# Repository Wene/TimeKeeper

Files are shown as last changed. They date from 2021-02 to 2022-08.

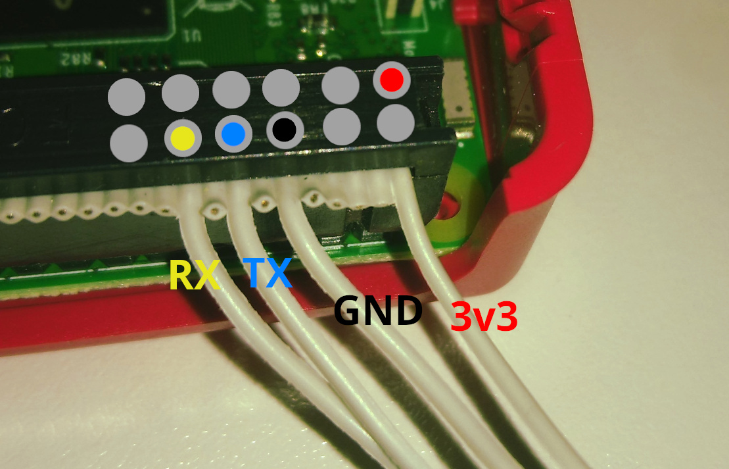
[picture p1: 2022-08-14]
img/Raspi_connector_with_description.jpg

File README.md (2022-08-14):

# TimeKeeper

## Project Goal

An open source, simple, and cheap solution for work time collection.

## Components

Every TimeKeeper collection point is equipped with a Raspberry Pi and some electronic components for RFID communication. In the only so far implemented version, those are a display and an RFID reader for the communication with the users and an Arduino to abstract the communication between the other electronic components and the Raspberry Pi. (See the schematics below)

Then, there is a desktop software written in Python using the PyQt libraries to view and manage the data. It's quite minimal at the moment. But as usage grows, the desktop client should be able to grow as well.

### Arduino Abstraction

The abstraction over the Arduino was chosen because there are some well established libraries available to interface with the display and the RFID reader. Of course, on the Raspberry Pi there are also libraries available to communicate directly with those components. But those aren't part of the main OS distribution. So on every update, we would have to take care to maintain compatibility. And since the Raspberrys are connected to the network, keeping them up to date is highly recommended. The serial interface used to communicate to the Arduino is part of the main distribution. On the other hand, the Arduino is not connected to the network and therefore less susceptible to attacks. And those libraries are way better integrated and available for a wide range of components in Arduino and PlatformIO. So in the future it should be simple to extend the system by other display and RFID reader types by just small changes in the PlatformIO code.

## Schematics

```
                  ┌───────────────────────────────────────────────────┐
                  │                                                   │
                  │            ┌──────────────────────────────────────┼──┐
                  │            │                                      │  │
┌─────────────────┴────────┐   │              ┌──────────────────┐    │  │
│                          │   │              │                  │    │  │
│                3v3   5v0 │   │              │ Arduino          │    │  │
│                          │   │              │ Pro Mini         │    │  │
│                      5v0 │   │              │ 328P 3v3 8 MHz   │    │  │
│   Raspberry Pi           │   │              │                  │    │  │
│                      GND ├───┘        ┌─────┤ TX               │    │  │
│                          │            │     │                  │    │  │
│                      TXD ├────────────┼─────┤ RX           GND ├────┼──┤
│                          │            │     │                  │    │  │
│                      RXD ├────────────┘     │                  │    │  │
│                          │                  │                  │    │  │
│                          │                  │              VCC ├────┤  │
└──────────────────────────┘                  │                  │    │  │
                                              │                  │    │  │                      ┌───────────────────────┐
                                        ┌─────┼─── A5 (SCL)      │    │  │                      │                       │
┌─────────────────────────────┐         │     │               10 ├────┼──┼──────────────────────┤ SDA                   │
│                             │         │  ┌──┼─── A4 (SDA)      │    │  │                      │                       │
│                         GND ├──────┐  │  │  │               11 ├────┼──┼───────────────┐  ┌───┤ SCK                   │
│                             │      │  │  │  │                  │    │  │               │  │   │                       │
│                         VCC ├───┐  │  │  │  │               12 ├────┼──┼────────────┐  └──┼───┤ MOSI                  │
│ Display (3V3 tolerant)      │   │  │  │  │  │                  │    │  │            │     │   │                       │
│                         SDA ├───┼──┼──┼──┘  │               13 ├────┼──┼─────────┐  └─────┼───┤ MISO                  │
│                             │   │  │  │     │                  │    │  │         │        │   │           RFID-RC522  │
│                         SCL ├───┼──┼──┘     │               A0 ├────┼──┼──────┐  └────────┘   │ IRQ                   │
│                             │   │  │        │                  │    │  │      │               │                       │
└─────────────────────────────┘   │  │        └──────────────────┘    │  ├──────┼───────────────┤ GND                   │
                                  │  │                                │  │      │               │                       │
                                  │  └────────────────────────────────┼──┘      └───────────────┤ RST                   │
                                  │                                   │                         │                       │
                                  └───────────────────────────────────┴─────────────────────────┤ 3v3                   │
                                                                                                │                       │
                                                                                                └───────────────────────┘
```

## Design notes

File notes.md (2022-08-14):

# Notes for project TimeKeeper

## Raspberry Pi

### Links
- [UART configuration](https://www.raspberrypi.com/documentation/computers/configuration.html#configuring-uarts)
- [GPIO general](https://www.raspberrypi.com/documentation/computers/os.html#gpio-and-the-40-pin-header)
- [Pin header schema](https://www.raspberrypi.org/documentation/hardware/raspberrypi/schematics/rpi_SCH_3bplus_1p0_reduced.pdf)

### Activating UART on GPIO header
Execute `raspi-config` and navigate to `3 interface options > Serial`. Here enable the UART interface but disable the default console on it. Reboot the RasPi after finishing those settings. To access the UART serial interface, the user needs to be in the groups `dialout` and `tty`.

### Test the connection
Use the command `screen /dev/ttyS0 115200` to open a screen session on the embedded UART serial interface at 115200 baud. Make sure something like an FTDI USB adapter is connected to that interface and configured to use the same data rate. You can now type in the screen session and your input should appear on the other side and vice versa.

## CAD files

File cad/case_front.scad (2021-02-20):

$fn = 100; 

module display_cut(){
    width = 72;
    height = 25;
    depth = 7;
    translate([-width/2, -height/2, 0]) cube([width, height, depth]);

    border = 8;
    top_width = width + 2*border;
    top_height = height + 2*border;
    top_thick = 10;
    translate([-top_width/2, -top_height/2, depth]) cube([top_width, top_height, top_thick]);

    step = 4;
    step_width = width-4;
    step_height = height-4;
    translate([-top_width/2, -step_height/2, step]) cube([top_width, step_height, top_thick]);
    translate([-step_width/2, -top_height/2, step]) cube([step_width, top_height, top_thick]);
}

module reader_dent(){
    width = 60 + 1;
    height = 40 + 1;
    depth = 1.6;
    pin_depth = 4;
    pin_width = 11;
    translate([-width/2, -height/2, -depth]) cube([width, height, depth]);
    translate([-width/2, -height/2, -pin_depth]) cube([pin_width, height, pin_depth]);
    translate([width/2-pin_width, -height/2, -pin_depth]) cube([pin_width, height, pin_depth]);
}

module case_front(){
    wall = 8;
    inner_width = 110;
    width = inner_width + 2*wall;
    inner_height = 100;
    height = inner_height + 2*wall;
    depth = 60;
    
    difference(){
        translate([-width/2, -height/2, 0]) cube([width, height, depth]);
        translate([-inner_width/2, -inner_height/2, wall]) cube([inner_width, inner_height, depth-wall+0.01]);
        translate([0, 26, -0.01]) display_cut();
        translate([0, -20, 8.01]) reader_dent();
    }
}

case_front();

/*
difference(){
    translate([-40, -75, 0]) cube([80, 150, 30]);
    translate([-32, -67, 8]) cube([64, 134, 23]);
    translate([-25, 40, -1]) cube([50, 15, 10]);
    translate([-30, 38, 5]) cube([60, 19, 5]);
}

*/

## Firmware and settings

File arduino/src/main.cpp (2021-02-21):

#include <Arduino.h>
#include "display.h"
#include "rfid.h"
#include "host.h"

#define VERSION F("0.1.0")

Display display;
Host host(display);
Rfid *rfid;

void setup()
{
  Serial.begin(9600);
  Serial.println(F("Booting TimeKeeper IO module..."));

  Serial.println(F("Searching for I2C display..."));
  uint8_t addr = display.init();
  String text = F("Booting...");
  display.print(0, text);
  Serial.print(F("Display found at address 0x"));
  Serial.println(addr, HEX);

  rfid = new Rfid;
  Serial.println(F("RFID module initialized"));

  Serial.print(F("TimeKeeper IO module ready ("));
  Serial.print(VERSION);
  Serial.println(")");

  text = F("Waiting for host");
  display.print(1, text);
}

String card_id;

void loop()
{
  unsigned long now = millis();

  if(rfid->new_card_id(card_id))
  {
    Serial.print(F("Card ID: "));
    Serial.println(card_id);
  }

  host.communicate(now);
}

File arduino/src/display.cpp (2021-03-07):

#include "display.h"
#include <Wire.h>


Display::Display()
{
  hour_glass_pos = 0;
}

Display::~Display()
{
  if(lcd)
  {
    delete lcd;
  }
}

uint8_t Display::init()
{
  uint8_t found_addr = 0;
  while(0 == found_addr)  // Endless loop until a display was found - makes sure lcd is not NULL.
  {
    Wire.begin();
    for(uint8_t addr = 0; addr <= 127; addr++)
    {
      // Test I²C address
      Wire.beginTransmission(addr);
      uint8_t error = Wire.endTransmission();

      // Enable display when address was found
      if(error == 0)
      {
        found_addr = addr;
        lcd = new LiquidCrystal_PCF8574(addr);
        lcd->begin(16, 2);
        lcd->setBacklight(255);
        lcd->clear();
        lcd->home();
        break;
      }
    }
    Wire.end();
  }

  define_hourglass_character();
  define_umlaut_character();

  return found_addr;
}

#define NO_CHAR byte(4)
#define AUML byte(5)
#define OUML byte(6)
#define UUML byte(7)

void Display::print(uint8_t line, String &text)
{
  lcd->setCursor(0, line);

  unsigned int out_pos = 0;
  unsigned int str_pos = 0;
  while(str_pos < text.length() && out_pos < 16)
  {
    char c = text.charAt(str_pos++);
    if((c >= 32 && c <= 91) || (c >= 93 && c <= 95) || (c >= 97 && c <= 125))
    {
      lcd->print(c);
    }
    else if((char)195 == c)
    {
      // utf-8 umlauts
      c = text.charAt(str_pos++);
      switch(c)
      {
      default:
        lcd->write(NO_CHAR);
        break;
      case (char)164:
        lcd->write(AUML);
        break;
      case (char)182:
        lcd->write(OUML);
        break;
      case (char)188:
        lcd->write(UUML);
        break;
      }
    }
    else
    {
      lcd->write(NO_CHAR);
    }
    out_pos++;
  }
  while(out_pos < 16)
  {
    lcd->print(" ");
    out_pos++;
  }
}

void Display::clear()
{
  lcd->clear();
}

void Display::hourglass_step()
{
  lcd->setCursor(15, 0);
  lcd->write(hour_glass_pos);
  hour_glass_pos++;
  if(hour_glass_pos > 3)
  {
    hour_glass_pos = 0;
  }
}

void Display::define_umlaut_character()
{
  byte no_char[8] =
  {
    B11111,
    B10001,
    B10001,
    B10001,
    B10001,
    B10001,
    B10001,
    B11111,
  };
  lcd->createChar(NO_CHAR, no_char);

  byte auml[8] =
  {
    B01010,
    B00000,
    B01110,
    B00001,
    B01111,
    B10001,
    B01111,
    B00000,
  };
  lcd->createChar(AUML, auml);

  byte ouml[8] =
  {
    B01010,
    B00000,
    B01110,
    B10001,
    B10001,
    B10001,
    B01110,
    B00000,
  };
  lcd->createChar(OUML, ouml);

  byte uuml[8] =
  {
    B01010,
    B00000,
    B10001,
    B10001,
    B10001,
    B10011,
    B01101,
    B00000,
  };
  lcd->createChar(UUML, uuml);
}

void Display::define_hourglass_character()
{
  byte hour_0[8] =
  {
    B11111,
    B11111,
    B11111,
    B01110,
    B01010,
    B10001,
    B10001,
    B11111,
  };
  lcd->createChar(0, hour_0);

  byte hour_1[8] =
  {
    B11111,
    B10001,
    B11111,
    B01110,
    B01010,
    B10001,
    B11111,
    B11111,
  };
  lcd->createChar(1, hour_1);

  byte hour_2[8] =
  {
    B11111,
    B10001,
    B10001,
    B01110,
    B01010,
    B11111,
    B11111,
    B11111,
  };
  lcd->createChar(2, hour_2);

  byte hour_3[8] =
  {
    B11111,
    B10001,
    B10001,
    B01010,
    B01110,
    B11111,
    B11111,
    B11111,
  };
  lcd->createChar(3, hour_3);
}

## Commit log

2021-02-14 design first case front draft
    [case_front.scad]
2021-02-20 empty line before printing a new one and limit output to display lenth
2021-02-20 adjust depth to resulting model
    [case_front.scad]
2021-02-22 new method to directly print input from serial
2021-05-25 disable button when not connected
2021-05-27 debug print output for new owners
2022-04-23 add schematic
2022-04-23 remove project file from git
    use the following command to generate it:
    platformio init --board pro8MHzatmega328 --ide qtcreator
2022-08-13 add owners filter
2022-08-13 filter case insensitive
2022-08-14 write some readme text and move over the schematics
2022-08-14 add image for the RasPi connector
2022-08-16 introduce filter in events list
2022-08-23 apply filter on event list update
